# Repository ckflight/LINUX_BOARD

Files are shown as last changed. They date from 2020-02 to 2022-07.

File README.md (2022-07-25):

# Embedded Linux Board Running Custom Linux Distribution

### Project Info:

 * AT91SAM9N12 Microprocessor with Memory Management Unit based Embedded Linux Board hardware and operating system files.
It has 133 MHz RAM and 4 Gb NAND Flash and QSPI Flash Interfaces.

 * This design is the custom version of SAM9N12-EK. The custom design has a RAM with different speed and latency, also it is using NAND Flash as a memory. Therefore, AT91Bootstrap Hardware initialization files must be customized accordingly. Briefly, the PLL and clocking settings as well as RAM latency values and NAND interface pinouts are changed accordingly. To see the details of the changes, please check **LINUX_BOARD/Linux_Files/At91bootstrap Files/at91sam9n12ek.c and .h** files. 

 * Buildroot is used for custom linux distribution. Check step by step guide below for details. Follow Ubuntu, u-boot and buildroot versions strictly as indicated below to make it compile properly.

### Final Board Screenshots:



linux board



### Important Notes: 

 * Use TeraTerm on Windows or Picocom on Mac OSx to be able to set the baud rate to 118200 8bit no parity 1 stop. The reason of this baudrate is that, In AT91Bootstrap, cpu clock is configured from 400MHz to 300MHz for changing RAM speed from 133MHz to 100MHz. Since PLL multipliers are not strickly generating 300 and 100 MHz, the actual speeds are 301.333 MHz and 101.333. This main clock difference changes all other peripherals' clocking. As result of this, characters are not received correctly when the baudrate is set to 115200. When the baudrate is set to 118200 on HOST side, the hardware and the HOST side can talk without any issue. **(However in buildroot, u-boot and AT91Bootstrap files the uart is configured to 115200 8N1 no parity)**
 
 * The steps below are tested with UBUNTU 16.04.6 and 18.04.2 LTS.
 
### STEP BY STEP GUIDE FOR FLASHING BOARD TO RUN LINUX 
  
#### 1. This part describes how board is connected over USB and what commands needed to see on sam_ba program

   If linux board is new and fresh then connect over usb to linux virtual computer
   If linux board is flashed previously with files then connect nandflash's pin41 to ground and plug usb
   Linux will see device as /dev/ttyACM0 but sam_ba cannot see so type command (It is required every time): 
   
   	sudo chmod a+rw /dev/ttyACM0
   
   Or add read write permission to usb device to not write above command every time.To do that, 
   go to /etc/udev/rules.d and create a rule file such as myusb.rules file and add the line
 	
	sudo nano /etc/udev/rules.d/filename.rules
	KERNEL=="ttyACM[0-9]*",MODE="0666"

    Now sam-ba can see board as /dev/ttyACM0

#### 2. Before start install these libraries:

	1. sudo apt install libncurses5 libncursesw5-dev libncurses5-dev
	2. sudo apt install make
	3. sudo apt install gcc-arm-linux-gnueabi
	4. sudo apt install gcc
	5. sudo apt install g++
	6. sudo apt install python
        (these might no be needed)
	7. sudo apt install make-guile
	8. sudo apt install gcc-multilib
	9. sudo apt install gcc-arm*

	Files required for board and in this part they will be created:
	A. AT91SAMBOOTSTRAP 	(Initialises SAM9N12E hardware like clock, nano interface scram gpio etc.)
	B. U-BOOT    		(Initialises SAM9N12E hardware clk, ram and etc.)
	C. BUILDROOT 		(LINUX KERNEL + ROOTFS (Our python c compiler nano etc apps are in rootfs) )

#### 2.1 How to compile and create at91sambootstrap files:
 
   I put at91bootstrap-3-3.8.tar.gz, it is the latest version and works
   unzip to Ubuntu and use it. For any case download link is below:
	
	http://repository.timesys.com/buildsources/a/at91bootstrap-3/

   Go to at91bootstrap-3-3.8 folder and change 

 	/at91bootstrap-3-3.8/board/at91sam9n12ek/at91sam9n12ek.c and .h files
 
   with

 	/at91bootstrap Files/at91sam9n12ek.c and .h
 
   Go to the at91bootstrap-3-3.8 folder location over terminal and apply commands

	1. make mrproper

	2. make at91sam9n12eknf_uboot_defconfig (nf means it will be loaded to nandflash, and u-boot means it will run u-boot)

	3. make menuconfig 			(this will open a configuration window)
	   3.1.Go to RAM Configuration and change RAM size to 64M
	   3.2 Go to NAND Flash configuration and change PMECC Error Correction Bits to 4bits, Sector to 512
	   3.3 Go to U-Boot Image Storage Setup and change External Ram Address to Load U-Boot Image from
               0x26F00000 to 0x22000000
	   3.4 Save an Alternate File and it will create .config file in at91bootstrap-3-3.8.(It is invisible nano .config opens if needed.)

	4. make CROSS_COMPILE=arm-linux-gnueabi-

	RESULT: The at91sam9n12ek-nandflashboot-uboot-3.8-beta1.bin file is ready in binaries file

#### 2.2 How to compile and create u-boot files:

   I put u-boot-2015.1.tar.gz to folder no need to download newer versions since include files naming are changed
   and they are not compiling without error. Unzip it to Ubuntu and use. For any case download link is below:

	 http://repository.timesys.com/buildsources/u/u-boot/

   Go to folder and change

	u-boot-2015.01/board/atmel/at91sam9n12ek/at91sam9n12ek.c file 
	with 
	/u-boot Files/at91sam9n12ek.c

    and

	u-boot-2015.01/include/configs/at91sam9n12ek.h file 
	with	
	/u-boot Files/at91sam9n12ek.h
	
    also For Ubuntu 16.04 gcc5.h, For Ubuntu 18.04 gcc7.h add (they have same code inside as well)

	/u-boot Files/compiler-gcc5.h or gcc.7 file
	to
	u-boot-2015.01/include/linux folder

   Go to u-boot-2015.01 folder with terminal and apply commands

	1. make mrproper

	2. make at91sam9n12ek_nandflash_defconfig (nandflash means this file will be written to nandflash)

	3. make CROSS_COMPILE=arm-linux-gnueabi-

	RESULT: The u-boot.bin is in u-boot-2015.01 folder

#### 2.3 How to compile and create build root files:
   
   I put buildroot-2015.2.tar.gz to folder and this version works. For any case download link is below:

	https://buildroot.org/downloads/

   Before start: Buildroot might create errors during compile. 
                 These are mostly package version collision type errors.
                 I look for error file and try to correct them. 
		 If i cannot then i disable that package with "make menuconfig" window.
                 Update when Ubuntu 16.04 is used: In buildroot-2015.2 it gave error i added correction files
		 Update when Ubuntu 18.04 is used: In buildroot-2015.2 it gave error i added correction files

   I used ready linux binary tree files with config files. (Read Linux Embedded Notes 5. DEVICE TREE: part for details of device tree .dts file)
  
   Go to /Buildroot_Files folder and copy 3 files from

	/Buildroot Files/
	to
	/buildroot-2015.02 main folder

   and then rename config-buildroot file as .config (it will be invisible after name change use terminal to see)

   Go to the buildroot-2015.02 folder and apply commands

	(To configure linux kernel to enable drivers use "make linux-menuconfig" command)
   	(for example wifi usb dongle drivers are enabled in linux menuconfig)

	1. make mrproper or make clean

	2. make menuconfig(if i want to add or change something)

	3. make

	RESULT: The files are in buildroot-2015.02/output/images

   Correction if Ubuntu 2016.04 is used (These can be applied when they occur during compilation): 
   	
	if an error not listed below happens first try to remove the installed package from "/output/build" and make again	

	a. ncrses:		copy the code in Buildroot_Correction/ncrse5.9_correction/MKlib_gen.sh 
                                and paste inside of (do not copy paste files itself copy paste code)
                                buildroot-2015.02/output/build/host-crse5.9/ncrse/base/Mklib_gen.sh
	
	c. host-mtd1.5.1: 	(DO THIS TO HOST-MTD NOT MTD folder) copy the code Buildroot_Correction/mkfsutil_correction
                                and paste to (do not copy paste file)
				buildroot-2015.02/output/build/host-mtd1.5.1/mkfs.ubifs/hashtable

   Correction if Ubuntu 2018.04 is with gcc 5 used (These can be applied when they occur during compilation):
   (All error corrections are added below. If could not make it work use Ubuntu 16.04) 
   	
	a. libffi3.1: 		change Buildroot_Correction/libffi3.1_correction/automake file 
				with 
				buildroot-2015.02/output/host/user/bin/automake
	
	b. libglib2.42:         (DO THIS TO LIBGLIB NOT HOST-LIBGLIB folder) change Buildroot_Correction/libglib2.42_correction/gdate.c file
				with
				buildroot-2015.02/output/build/libglib2.42/glib/gdate.c

	c. lzop1.03:            copy the code Buildroot_Correction/lzop1.03_correction/miniacc.f file
                                and paste to (do not copy paste file)
				buildroot-2015.02/output/build/host-lzop1.03/src/miniacc.h

	d. ncrses:		copy the code Buildroot_Correction/ncrse5.9_correction/MKlib_gen.sh 
                                and paste to (do not copy paste file)
                                buildroot-2015.02/output/build/host-crse5.9/ncrse/base/Mklib_gen.sh
	
	e. host-mtd1.5.1: 	(DO THIS TO HOST-MTD NOT MTD folder) copy the code Buildroot_Correction/mkfsutil_correction
                                and paste to (do not copy paste file)
				buildroot-2015.02/output/build/host-mtd1.5.1/mkfs.ubifs/hashtable

#### 3. How to flash files to board:

   Memory locations of files
	
	* at91sam9n12ek-nandflashboot-uboot-3.8.bin -----> 0x00

	* u-boot.bin				     -----> 0x40000

	* at91sam9n12_sam_board_3.15.dtb	     -----> 0x180000

	* uImage.bin				     -----> 0x200000

	* rootfs.ubi				     -----> 0x800000

   Unzip /sam-ba to ubuntu and connect board over usb (see 1) then click connect.
   Select "NandFlash" tab and from Scripts select "Enable NandFlash" click execute button.
   It should print as below:

	-I- NANDFLASH::Init (trace level : 4)
	-I- Loading applet applet-nandflash-sam9n12.bin at address 0x20000000
	-I- Memory Size : 0x20000000 bytes
	-I- Buffer address : 0x20011404
	-I- Buffer size: 0x20000 bytes
	-I- Applet initialization done

   Then again from Scripts select "Pmecc configuration" click execute button.
   (I think it reads nandflash auto but do anyway because when wrong parameters selected it gives error.)
   Select ECC bit: 4
   Select Sector size: 512

   It should print as below:
	-I- Ecc type is 2 Ecc Status is 2
	-I- Configure trimffs 0
	-I- PMECC c0082805 to be Configured
	-I- Pmecc header configration successful
	-I- PMECC configure c0082805   

#### 3.1. Set Address to 0x00 and from Scripts select "Send Boot File" click execute button.  
      Select at91sam9n12ek-nandflashboot-uboot-3.8.bin file and click open.

      It should print as below:
	   -I- Sending boot file done.

   From now on execute button will not be used. Rest of the files will send with
   "Send File Name" folder selector and address setting.

#### 3.2. Set Address to 0x40000 and from "Send File Name" folder selector 
      select "u-boot.bin" file and click "Send File".

      It should print as below:
	   -I- Send File /home/ck/Desktop/u-boot.bin at address 0x40000
	   GENERIC::SendFile /home/ck/Desktop/u-boot.bin at address 0x40000
	   -I- File size : 0x5CD30 byte(s)
	   -I- 	Writing: 0x20000 bytes at 0x40000 (buffer addr : 0x20011404)
	   -I- 	0x20000 bytes written by applet
	   -I- 	Writing: 0x20000 bytes at 0x60000 (buffer addr : 0x20011404)
	   -I- 	0x20000 bytes written by applet
	   -I- 	Writing: 0x1CD30 bytes at 0x80000 (buffer addr : 0x20011404)
	   -I- 	0x1CD30 bytes written by applet

#### 3.3. Set Address to 0x180000 and from "Send File Name" folder selector 
      select "at91sam9n12_sam_board_3.15.dtb" file and click "Send File".
      
      It should print as below:
	   -I- Send File /home/ck/Desktop/at91sam9n12_sam_board_3.15.dtb at address 0x180000
	   GENERIC::SendFile /home/ck/Desktop/at91sam9n12_sam_board_3.15.dtb at address 0x180000
	   -I- File size : 0x2966 byte(s)
	   -I- 	Writing: 0x2966 bytes at 0x180000 (buffer addr : 0x20011404)
	   -I- 	0x20000 bytes written by applet

#### 3.4. Set Address to 0x200000 and from "Send File Name" folder selector 
      select "uImage.bin" file and click "Send File".
      
      It should print as below:

	   -I- Send File /home/ck/Desktop/uImage.bin at address 0x200000
	   GENERIC::SendFile /home/ck/Desktop/uImage.bin at address 0x200000
	   -I- File size : 0x2B91F0 byte(s)
	   -I- 	Writing: 0x20000 bytes at 0x200000 (buffer addr : 0x20011404)
	   -I- 	0x20000 bytes written by applet
	   ... goes like this
	   -I- 	Writing: 0x191F0 bytes at 0x4A0000 (buffer addr : 0x20011404)
	   -I- 	0x191F0 bytes written by applet

#### 3.5. Set Address to 0x800000 and from "Send File Name" folder selector 
      select "rootfs.ubi" file and click "Send File".

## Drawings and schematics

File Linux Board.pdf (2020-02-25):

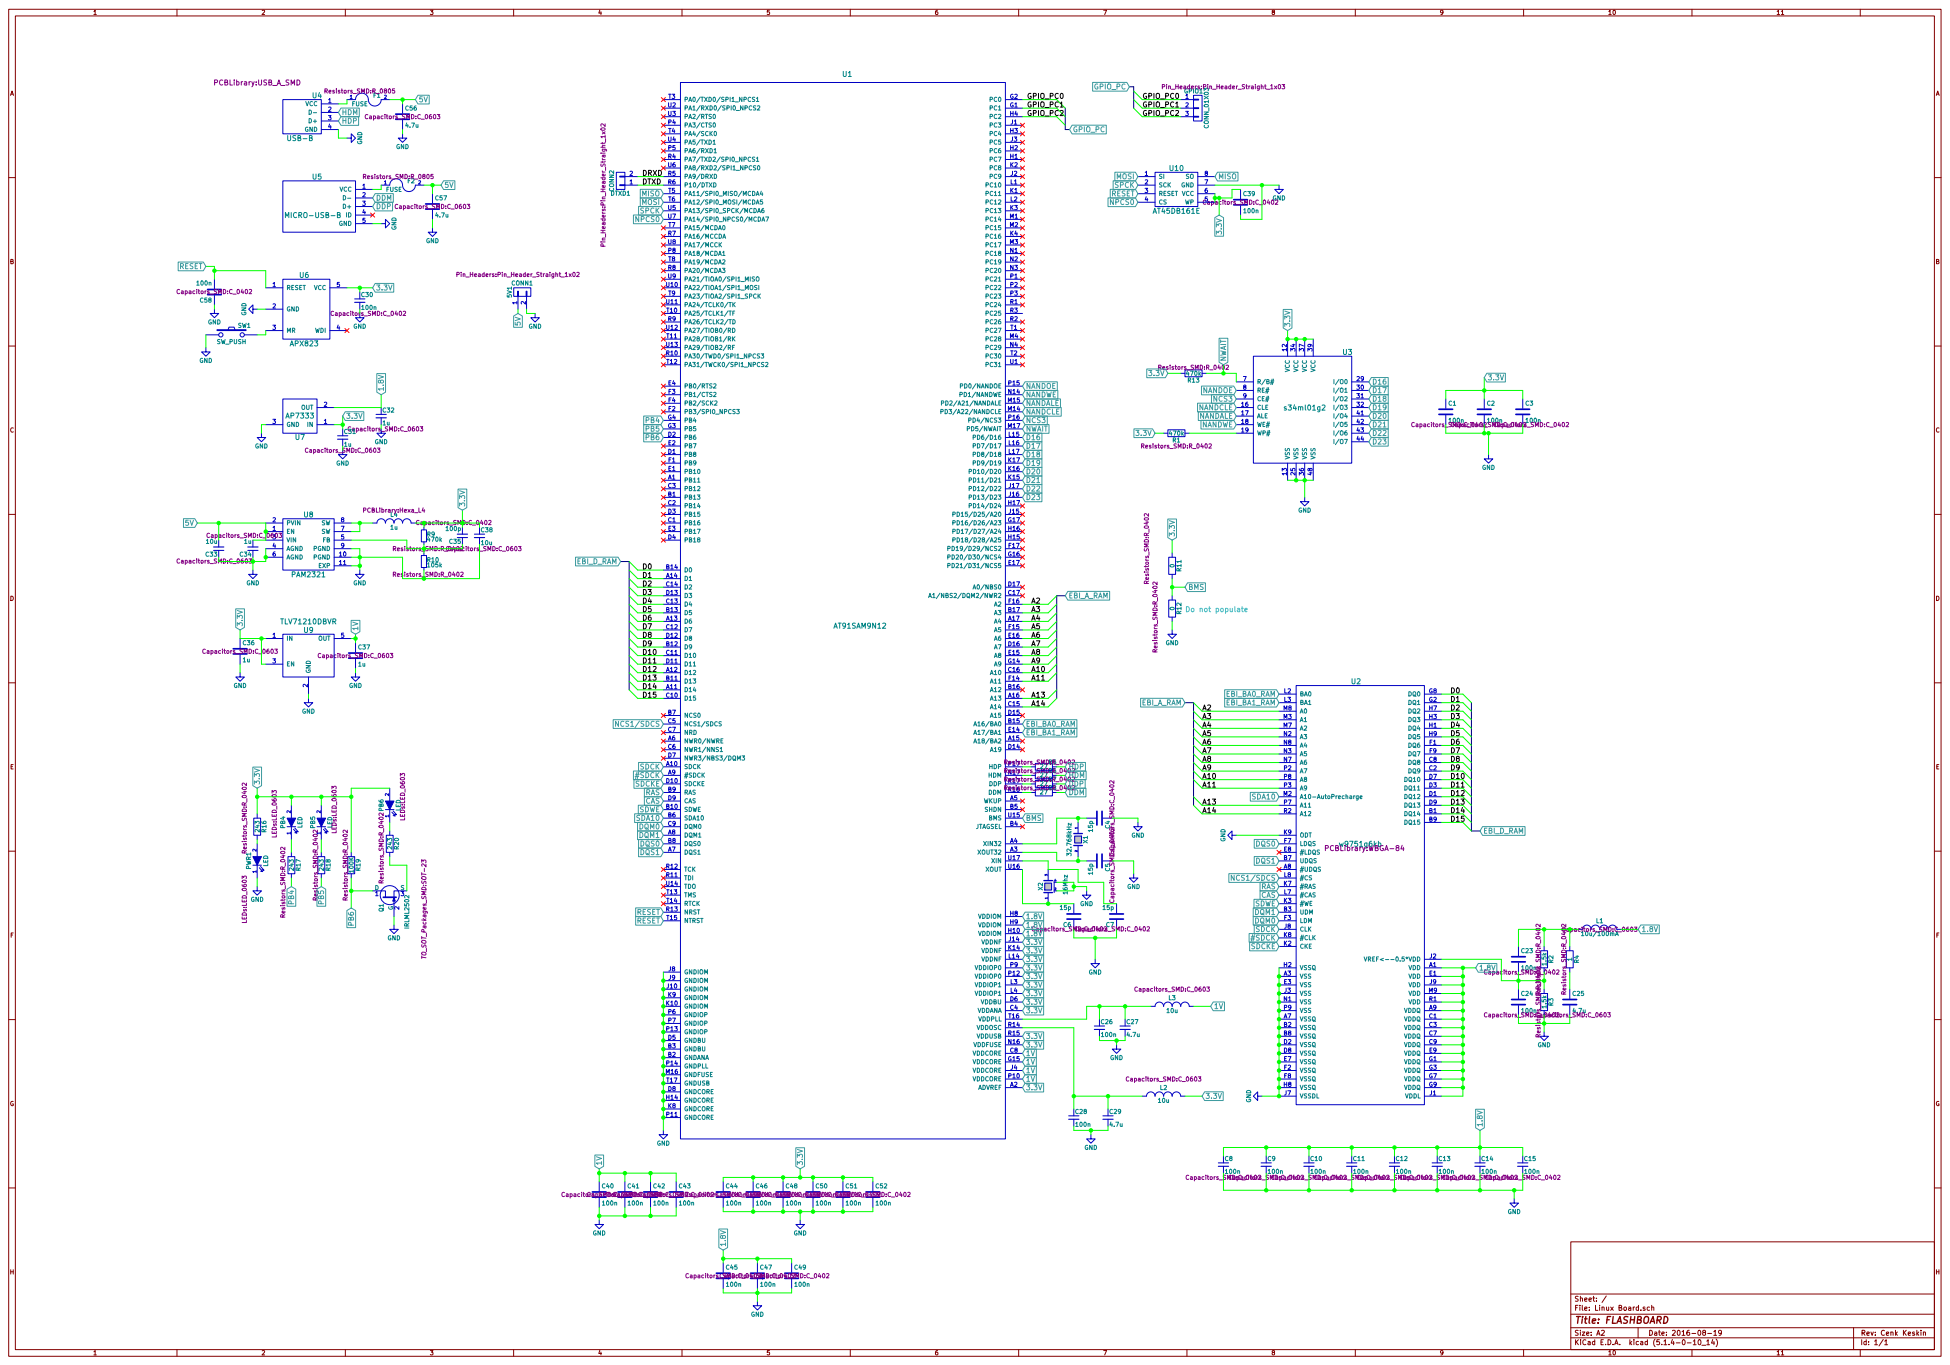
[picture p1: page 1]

File: Linux Board.sch Sheet: /
Id: 1/1 Title: FLASHBOARD

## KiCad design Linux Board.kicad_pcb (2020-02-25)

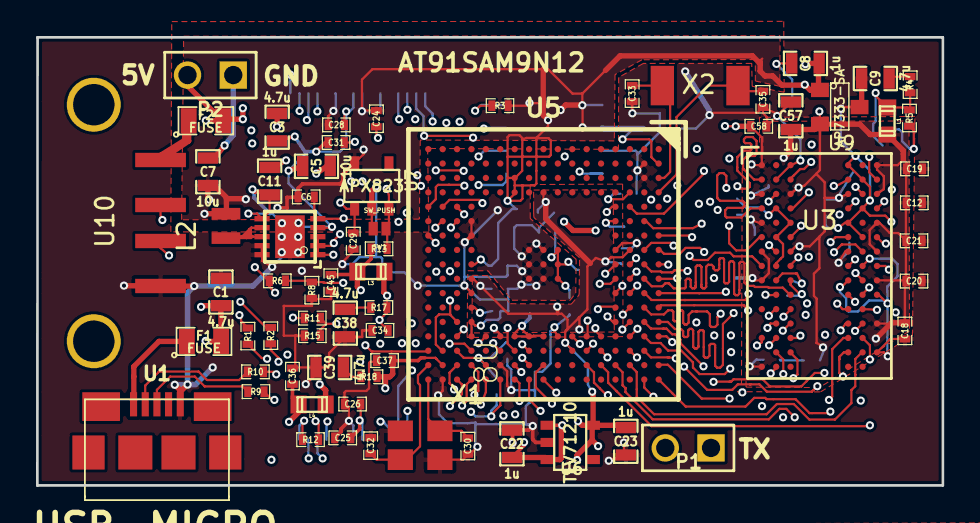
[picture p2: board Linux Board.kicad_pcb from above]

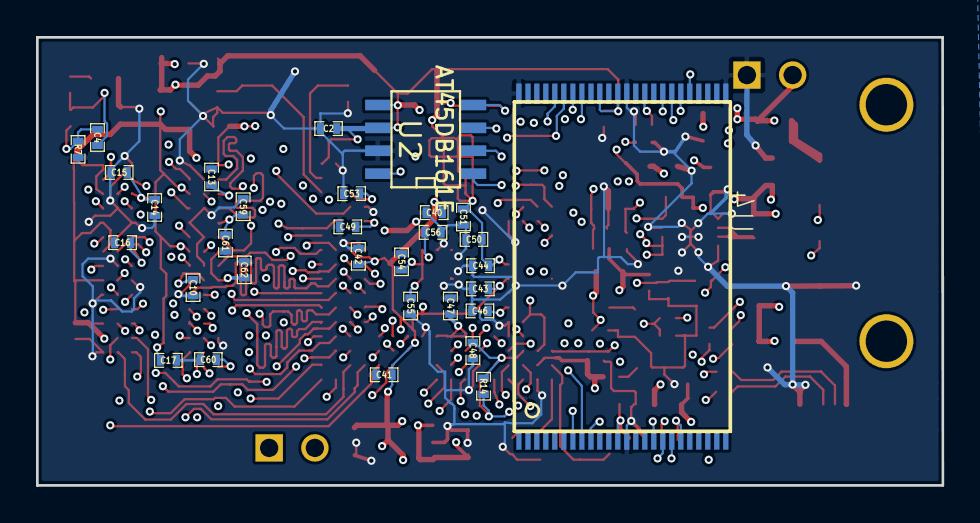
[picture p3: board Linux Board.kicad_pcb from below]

Board: 4 copper layers, 50.3 x 24.9 mm, 98 parts (31 on the bottom side), 94 nets.

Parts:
C1, C3, C9, C38, C39: 4.7u; SM0603_Capa
C2, C4, C10, C12, C13, C14, C15, C16, C17, C18, C19, C20, C21, C24, C25, C26, C28, C29, C31, C34, C36, C37, C40, C41, C42, C43, C44, C45, C46, C47, C48, C49, C50, C51, C53, C54, C55, C56, C58, C59, C60, C61, C62: 100n; SM0402_c
C5, C7: 10u; SM0603_Capa
C6: 100p; SM0402_c
C8, C11, C22, C23, C57: 1u; SM0603_Capa
C30, C32, C33, C35: 15p; SM0402_c
F1, F2: FUSE; SM0805
L1, L3, L4: 10u/100mA; c_0603
L2: 1.0u/1.5A; VLS201612E
P1, P2: CONN_2; PIN_ARRAY_2X1
R1, R2, R9, R10: 27; SM0402_r
R3, R12, R14: 470k; SM0402_r
R4, R17, R18: 1; SM0402_r
R5, R7: 1.5k; SM0402_r
R6: 450k; SM0402_r
R8: 100k; SM0402_r
R11, R15: 0; SM0402_r
R13: 10k; SM0402_r
SW1: SW_PUSH; S_JUMPER_2
U1: USB-MICRO; MICRO-B_USB
U2: AT45DB161E; SO8E
U3: W9751G6KB; WBGA-84
U4: PAM2321; DFN10-3X3
U5: AT91SAM9N12; lfbga217-std
U6: TLV71210; SOT23-5
U7: APX823; SOT23-5
U8: S34ML04G2; TSOP48
U9: AP7333-SA; SOT23
U10: USB-A; USB-A-SMD
X1: 16MHz; TSX-3225
X2: 32.768kHz; ABS10

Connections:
1V: C23.1, C36.1, C40.1, C41.1, C42.1, C43.1, L4.1, U5.C8, U5.G15, U5.J4, U5.P10, U6.5
3V3: C2.1, C6.1, C7.1, C8.1, C22.1, C24.1, C25.1, C26.1, C28.1, C44.1, C45.1, C46.1, C47.1, C48.1, C49.1, C50.1, C51.1, C53.1, L2.2, L3.1, R3.2, R6.1, R11.2, R12.1, R13.1, R14.2, U2.5, U2.6, U5.A2, U5.C4, U5.D6, U5.J14, U5.K14, U5.L3, U5.L4, U5.L14, U5.N16, U5.P9, U5.P12, U5.R15, U6.1, U6.3, U7.5, U8.12, U8.34, U8.37, U8.39, U9.1
5V: C1.1, C3.1, C5.1, C11.1, F1.2, F2.2, P2.2, U4.1, U4.2, U4.3
+1.8V: C12.1, C13.1, C14.1, C15.1, C16.1, C17.1, C18.1, C19.1, C20.1, C21.1, C54.1, C55.1, C56.1, C57.1, C58.1, C59.1, C60.1, C61.1, C62.1, L1.1, U3.A1, U3.A9, U3.C1, U3.C3, U3.C7, U3.C9, U3.E1, U3.E9, U3.G1, U3.G3, U3.G7, U3.G9, U3.J1, U3.J9, U3.M9, U3.R1, U5.H8, U5.H9, U5.H10, U9.2
/A2: U3.M8, U5.F16
/A3: U3.M3, U5.B17
/A4: U3.M7, U5.A17
/A5: U3.N2, U5.F15
/A6: U3.N8, U5.E16
/A7: U3.N3, U5.D16
/A8: U3.N7, U5.E15
/A9: U3.P2, U5.G14
/A10: U3.P8, U5.C16
/A11: U3.P3, U5.F14
/A13: U3.P7, U5.A16
/A14: U3.R2, U5.C15
/A16/BA0: U3.L2, U5.B15
/A17/BA1: U3.L3, U5.E14
/CAS: U3.L7, U5.D9
/D0: U3.G8, U5.B14
/D1: U3.G2, U5.A14
/D2: U3.H7, U5.C14
/D3: U3.H3, U5.D13
/D4: U3.H1, U5.C13
/D5: U3.H9, U5.B13
/D6: U3.F1, U5.A13
/D7: U3.F9, U5.C12
/D8: U3.C8, U5.D12
/D9: U3.C2, U5.B12
/D10: U3.D7, U5.C11
/D11: U3.D3, U5.D11
/D12: U3.D1, U5.A12
/D13: U3.D9, U5.B11
/D14: U3.B1, U5.A11
/D15: U3.B9, U5.C10
/D16: U5.L15, U8.29
/D17: U5.L16, U8.30
/D18: U5.L17, U8.31
/D19: U5.K17, U8.32
/D20: U5.K16, U8.41
/D21: U5.K15, U8.42
/D22: U5.J17, U8.43
/D23: U5.J16, U8.44
/DQM0: U3.F3, U5.C9
/DQM1: U3.B3, U5.A8
/DQS0: U3.F7, U5.B8
/DQS1: U3.B7, U5.A7
/DRXD: P1.2, U5.R5
/DTXD: P1.1, U5.R6
/MISO0: U2.8, U5.T5
/MOSI0: U2.1, U5.T6
/NANDALE: U5.M15, U8.17
/NANDCLE: U5.M14, U8.16
/NANDCS: U5.P16, U8.9
/NANDOE: U5.P15, U8.8
/NANDWE: U5.N14, U8.18
/NCS1: U3.L8, U5.C5
/NPCS0: R3.1, U2.4, U5.U7
/NWAIT: R14.1, U5.M17, U8.7
/RAS: U3.K7, U5.B9
/SCK0: U2.2, U5.U5
/SDA10: U3.M2, U5.B6
/SDCK: U3.J8, U5.A10
/SDCKE: U3.K2, U5.D10
/SDCKN: U3.K8, U5.A9
/SDWE: U3.K3, U5.B10
/VDD_OSC: C34.1, L3.2, R17.2, U5.R14
/VDD_PLL: C37.1, L4.2, R18.2, U5.T16
GND: C1.2, C2.2, C3.2, C5.2, C7.2, C8.2, C9.2, C10.2, C11.2, C12.2, C13.2, C14.2, C15.2, C16.2, C17.2, C18.2, C19.2, C20.2, C21.2, C22.2, C23.2, C24.2, C25.2, C26.2, C28.2, C29.2, C30.1, C31.2, C32.1, C33.2, C34.2, C35.2, C36.2, C37.2, C38.2, C39.2, C40.2, C41.2, C42.2, C43.2, C44.2, C45.2, C46.2, C47.2, C48.2, C49.2, C50.2, C51.2, C53.2, C54.2, C55.2, C56.2, C57.2, C58.2, C59.2, C60.2, C61.2, C62.2, P2.1, R7.2, R8.1, R15.1, SW1.2, U1.5, U2.7, U3.A3, U3.A7, U3.B2, U3.B8, U3.D2, U3.D8, U3.E3, U3.E7, U3.F2, U3.F8, U3.H2, U3.H8, U3.J3, U3.J7, U3.K9, U3.N1, U3.P9, U4.4, U4.6, U4.9, U4.10, U4.EXP, U5.B2, U5.B3, U5.D5, U5.D8, U5.H14, U5.J8, U5.J9, U5.J10, U5.K8, U5.K9, U5.K10, U5.M16, U5.P6, U5.P7, U5.P11, U5.P13, U5.P14, U5.T17, U6.2, U7.2, U8.13, U8.25, U8.36, U8.48, U9.3, U10.4, X1.2, X1.4
unnamed: C4.2, C10.1, R5.2, R7.1, U3.J2
unnamed: L2.1, U4.7, U4.8
unnamed: C38.1, R17.1
unnamed: C6.2, R6.2, R8.2, U4.5
unnamed: F2.1, U10.1
unnamed: R2.1, U5.N17
unnamed: R1.1, U5.P17
unnamed: R12.2, U8.19
unnamed: C32.2, U5.U16, X1.1
unnamed: C39.1, R18.1
unnamed: C9.1, R4.2
unnamed: F1.1, U1.1
unnamed: R10.1, U5.R16
unnamed: R9.1, U5.R17
unnamed: R11.1, R15.2, U5.U15
unnamed: C31.1, R13.2, SW1.1, U7.3
unnamed: C30.2, U5.U17, X1.3
unnamed: C4.1, L1.2, R4.1, R5.1
unnamed: C35.1, U5.A4, X2.2
unnamed: C33.1, U5.A3, X2.1
USBDM: R10.2, U1.2
USBDP: R9.2, U1.3
USBHM: R2.2, U10.2
USBHP: R1.2, U10.3
~RESET: C29.1, U2.3, U5.R13, U5.T15, U7.1

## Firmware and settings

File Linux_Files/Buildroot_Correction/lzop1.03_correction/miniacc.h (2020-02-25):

/* ACC --- Automatic Compiler Configuration

   This file is part of the lzop file compressor.

   Copyright (C) 2010 Markus Franz Xaver Johannes Oberhumer
   Copyright (C) 2009 Markus Franz Xaver Johannes Oberhumer
   Copyright (C) 2008 Markus Franz Xaver Johannes Oberhumer
   Copyright (C) 2007 Markus Franz Xaver Johannes Oberhumer
   Copyright (C) 2006 Markus Franz Xaver Johannes Oberhumer
   Copyright (C) 2005 Markus Franz Xaver Johannes Oberhumer
   Copyright (C) 2004 Markus Franz Xaver Johannes Oberhumer
   Copyright (C) 2003 Markus Franz Xaver Johannes Oberhumer
   Copyright (C) 2002 Markus Franz Xaver Johannes Oberhumer
   Copyright (C) 2001 Markus Franz Xaver Johannes Oberhumer
   Copyright (C) 2000 Markus Franz Xaver Johannes Oberhumer
   Copyright (C) 1999 Markus Franz Xaver Johannes Oberhumer
   Copyright (C) 1998 Markus Franz Xaver Johannes Oberhumer
   Copyright (C) 1997 Markus Franz Xaver Johannes Oberhumerf
   Copyright (C) 1996 Markus Franz Xaver Johannes Oberhumer
   All Rights Reserved.

   lzop and the LZO library are free software; you can redistribute them
   and/or modify them under the terms of the GNU General Public License as
   published by the Free Software Foundation; either version 2 of
   the License, or (at your option) any later version.

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
   You should have received a copy of the GNU General Public License
   along with this program; see the file COPYING.
   If not, write to the Free Software Foundation, Inc.,
   59 Temple Place - Suite 330, Boston, MA 02111-1307, USA.

   Markus F.X.J. Oberhumer
   <markus@oberhumer.com>
   http://www.oberhumer.com/opensource/lzop/
 */


#ifndef __ACC_H_INCLUDED
#define __ACC_H_INCLUDED 1
#define ACC_VERSION     20101019L
#if defined(__CYGWIN32__) && !defined(__CYGWIN__)
#  define __CYGWIN__ __CYGWIN32__
#endif
#if defined(__IBMCPP__) && !defined(__IBMC__)
#  define __IBMC__ __IBMCPP__
#endif
#if defined(__ICL) && defined(_WIN32) && !defined(__INTEL_COMPILER)
#  define __INTEL_COMPILER __ICL
#endif
#if 1 && defined(__INTERIX) && defined(__GNUC__) && !defined(_ALL_SOURCE)
#  define _ALL_SOURCE 1
#endif
#if defined(__mips__) && defined(__R5900__)
#  if !defined(__LONG_MAX__)
#    define __LONG_MAX__ 9223372036854775807L
#  endif
#endif
#if defined(__INTEL_COMPILER) && defined(__linux__)
#  pragma warning(disable: 193)
#endif
#if defined(__KEIL__) && defined(__C166__)
#  pragma warning disable = 322
#elif 0 && defined(__C251__)
#  pragma warning disable = 322
#endif
#if defined(_MSC_VER) && !defined(__INTEL_COMPILER) && !defined(__MWERKS__)
#  if (_MSC_VER >= 1300)
#    pragma warning(disable: 4668)
#  endif
#endif
#if defined(__POCC__) && defined(_WIN32)
#  if (__POCC__ >= 400)
#    pragma warn(disable: 2216)
#  endif
#endif
#if 0 && defined(__WATCOMC__)
#  if (__WATCOMC__ >= 1050) && (__WATCOMC__ < 1060)
#    pragma warning 203 9
#  endif
#endif
#if defined(__BORLANDC__) && defined(__MSDOS__) && !defined(__FLAT__)
#  pragma option -h
#endif
#if (ACC_CFG_NO_CONFIG_HEADER)
#elif defined(ACC_CFG_CONFIG_HEADER)
#  include ACC_CFG_CONFIG_HEADER
#else
#endif
#if (ACC_CFG_NO_LIMITS_H)
#elif (ACC_LIBC_NAKED) || (ACC_BROKEN_LIMITS_H)
#ifndef __ACC_FALLBACK_LIMITS_H_INCLUDED
#define __ACC_FALLBACK_LIMITS_H_INCLUDED 1
#undef CHAR_BIT
#define CHAR_BIT        8
#ifndef MB_LEN_MAX
#define MB_LEN_MAX      1
#endif
#ifndef __SCHAR_MAX__
#define __SCHAR_MAX__   127
#endif
#ifndef __SHRT_MAX__
#define __SHRT_MAX__    32767
#endif
#ifndef __INT_MAX__
#define __INT_MAX__     2147483647
#endif
#ifndef __LONG_MAX__
#if defined(__alpha__) || defined(_LP64) || defined(__MIPS_PSX2__)
#define __LONG_MAX__    9223372036854775807L
#else
#define __LONG_MAX__    2147483647L
#endif
#endif
#undef SCHAR_MIN
#undef SCHAR_MAX
#undef UCHAR_MAX
#define SCHAR_MIN       (-1 - SCHAR_MAX)
#define SCHAR_MAX       (__SCHAR_MAX__)
#define UCHAR_MAX       (SCHAR_MAX * 2 + 1)
#undef SHRT_MIN
#undef SHRT_MAX
#undef USHRT_MAX
#define SHRT_MIN        (-1 - SHRT_MAX)
#define SHRT_MAX        (__SHRT_MAX__)
#if ((__INT_MAX__) == (__SHRT_MAX__))
#define USHRT_MAX       (SHRT_MAX * 2U + 1U)
#else
#define USHRT_MAX       (SHRT_MAX * 2 + 1)
#endif
#undef INT_MIN
#undef INT_MAX
#undef UINT_MAX
#define INT_MIN         (-1 - INT_MAX)
#define INT_MAX         (__INT_MAX__)
#define UINT_MAX        (INT_MAX * 2U + 1U)
#undef LONG_MIN
#undef LONG_MAX
#undef ULONG_MAX
#define LONG_MIN        (-1L - LONG_MAX)
#define LONG_MAX        ((__LONG_MAX__) + 0L)
#define ULONG_MAX       (LONG_MAX * 2UL + 1UL)
#undef CHAR_MIN
#undef CHAR_MAX
#if defined(__CHAR_UNSIGNED__) || defined(_CHAR_UNSIGNED)
#define CHAR_MIN        0
#define CHAR_MAX        UCHAR_MAX
#else
#define CHAR_MIN        SCHAR_MIN
#define CHAR_MAX        SCHAR_MAX
#endif
#endif
#else
#  include <limits.h>
#endif
#if 0
#define ACC_0xffffL             0xfffful
#define ACC_0xffffffffL         0xfffffffful
#else
#define ACC_0xffffL             65535ul
#define ACC_0xffffffffL         4294967295ul
#endif
#if (ACC_0xffffL == ACC_0xffffffffL)
#  error "your preprocessor is broken 1"
#endif
#if (16ul * 16384ul != 262144ul)
#  error "your preprocessor is broken 2"
#endif
#if 0
#if (32767 >= 4294967295ul)
#  error "your preprocessor is broken 3"
#endif
#if (65535u >= 4294967295ul)
#  error "your preprocessor is broken 4"
#endif
#endif
#if (UINT_MAX == ACC_0xffffL)
#if defined(__ZTC__) && defined(__I86__) && !defined(__OS2__)
#  if !defined(MSDOS)
#    define MSDOS 1
#  endif
#  if !defined(_MSDOS)
#    define _MSDOS 1
#  endif
#elif 0 && defined(__VERSION) && defined(MB_LEN_MAX)
#  if (__VERSION == 520) && (MB_LEN_MAX == 1)
#    if !defined(__AZTEC_C__)
#      define __AZTEC_C__ __VERSION
#    endif
#    if !defined(__DOS__)
#      define __DOS__ 1
#    endif
#  endif
#endif
#endif
#if defined(_MSC_VER) && defined(M_I86HM) && (UINT_MAX == ACC_0xffffL)
#  define ptrdiff_t long
#  define _PTRDIFF_T_DEFINED 1
#endif
#if (UINT_MAX == ACC_0xffffL)
#  undef __ACC_RENAME_A
#  undef __ACC_RENAME_B
#  if defined(__AZTEC_C__) && defined(__DOS__)
#    define __ACC_RENAME_A 1
#  elif defined(_MSC_VER) && defined(MSDOS)
#    if (_MSC_VER < 600)
#      define __ACC_RENAME_A 1
#    elif (_MSC_VER < 700)
#      define __ACC_RENAME_B 1
#    endif
#  elif defined(__TSC__) && defined(__OS2__)
#    define __ACC_RENAME_A 1
#  elif defined(__MSDOS__) && defined(__TURBOC__) && (__TURBOC__ < 0x0410)
#    define __ACC_RENAME_A 1
#  elif defined(__PACIFIC__) && defined(DOS)
#    if !defined(__far)
#      define __far far
#    endif
#    if !defined(__near)
#      define __near near
#    endif
#  endif
#  if defined(__ACC_RENAME_A)
#    if !defined(__cdecl)
#      define __cdecl cdecl
#    endif
#    if !defined(__far)
#      define __far far
#    endif
#    if !defined(__huge)
#      define __huge huge
#    endif
#    if !defined(__near)
#      define __near near
#    endif
#    if !defined(__pascal)
#      define __pascal pascal
#    endif
#    if !defined(__huge)
#      define __huge huge
#    endif
#  elif defined(__ACC_RENAME_B)
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

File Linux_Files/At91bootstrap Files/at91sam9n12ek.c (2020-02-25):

/* ----------------------------------------------------------------------------
 *         ATMEL Microcontroller Software Support
 * ----------------------------------------------------------------------------
 * Copyright (c) 2008, Atmel Corporation

 * All rights reserved.
 *
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
 * Atmel's name may not be used to endorse or promote products derived from
 * this software without specific prior written permission.
 *
 * DISCLAIMER: THIS SOFTWARE IS PROVIDED BY ATMEL "AS IS" AND ANY EXPRESS OR
 * IMPLIED WARRANTIES, INCLUDING, BUT NOT LIMITED TO, THE IMPLIED WARRANTIES OF
 * MERCHANTABILITY, FITNESS FOR A PARTICULAR PURPOSE AND NON-INFRINGEMENT ARE
 * DISCLAIMED. IN NO EVENT SHALL ATMEL BE LIABLE FOR ANY DIRECT, INDIRECT,
 * INCIDENTAL, SPECIAL, EXEMPLARY, OR CONSEQUENTIAL DAMAGES (INCLUDING, BUT NOT
 * LIMITED TO, PROCUREMENT OF SUBSTITUTE GOODS OR SERVICES; LOSS OF USE, DATA,
 * OR PROFITS; OR BUSINESS INTERRUPTION) HOWEVER CAUSED AND ON ANY THEORY OF
 * LIABILITY, WHETHER IN CONTRACT, STRICT LIABILITY, OR TORT (INCLUDING
 * NEGLIGENCE OR OTHERWISE) ARISING IN ANY WAY OUT OF THE USE OF THIS SOFTWARE,
 * EVEN IF ADVISED OF THE POSSIBILITY OF SUCH DAMAGE.
 */
#include "common.h"
#include "hardware.h"
#include "arch/at91_ccfg.h"
#include "arch/at91_rstc.h"
#include "arch/at91_pmc.h"
#include "arch/at91_smc.h"
#include "arch/at91_pio.h"
#include "arch/at91_ddrsdrc.h"
#include "gpio.h"
#include "pmc.h"
#include "usart.h"
#include "debug.h"
#include "ddramc.h"
#include "spi.h"
#include "slowclk.h"
#include "timer.h"
#include "watchdog.h"
#include "string.h"
#include "at91sam9n12ek.h"

#ifdef CONFIG_USER_HW_INIT
extern void hw_init_hook(void);
#endif

static void at91_dbgu_hw_init(void)
{
	/* Configure DBGU pin */
	const struct pio_desc dbgu_pins[] = {
		{"RXD", AT91C_PIN_PA(9), 0, PIO_DEFAULT, PIO_PERIPH_A},
		{"TXD", AT91C_PIN_PA(10), 0, PIO_DEFAULT, PIO_PERIPH_A},
		{(char *)0, 0, 0, PIO_DEFAULT, PIO_PERIPH_A},
	};

	/*  Configure the dbgu pins */
	pmc_enable_periph_clock(AT91C_ID_PIOA_B);
	pio_configure(dbgu_pins);
}

static void initialize_dbgu(void)
{
	at91_dbgu_hw_init();
	usart_init(BAUDRATE(MASTER_CLOCK, 115200));
}

#ifdef CONFIG_DDR2
/* Using the Micron MT47H64M16HR-3 */
static void ddramc_reg_config(struct ddramc_register *ddramc_config)
{
	ddramc_config->mdr = (AT91C_DDRC2_DBW_16_BITS
				| AT91C_DDRC2_MD_DDR2_SDRAM);

	ddramc_config->cr = (AT91C_DDRC2_NC_DDR10_SDR9	// 10 column bits (1K)
				| AT91C_DDRC2_NR_13	// 13 row bits    (8K)
				| AT91C_DDRC2_CAS_3	// CAS Latency 3
				| AT91C_DDRC2_NB_BANKS_4	// 8 banks
				| AT91C_DDRC2_DLL_RESET_DISABLED	// DLL not reset
				| AT91C_DDRC2_DECOD_INTERLEAVED);	// Interleaved decoding

	/*
	 * The DDR2-SDRAM device requires a refresh every 15.625 us or 7.81 us.
	 * With a 133 MHz frequency, the refresh timer count register must to be
	 * set with (15.625 x 133 MHz) ~ 2084 i.e. 0x824
	 * or (7.81 x 133 MHz) ~ 1040 i.e. 0x410.
	 */
	ddramc_config->rtr = 0x30D;	/* Refresh timer: 7.8125us */

	/* One clock cycle @ 133 MHz = 7.5 ns */
	ddramc_config->t0pr = (AT91C_DDRC2_TRAS_(2)
				| AT91C_DDRC2_TRCD_(2)
				| AT91C_DDRC2_TWR_(2)
				| AT91C_DDRC2_TRC_(6)
				| AT91C_DDRC2_TRP_(2)
				| AT91C_DDRC2_TRRD_(1)
				| AT91C_DDRC2_TWTR_(2)
				| AT91C_DDRC2_TMRD_(2));

	ddramc_config->t1pr = (AT91C_DDRC2_TXP_(2)
				| AT91C_DDRC2_TXSRD_(200)
				| AT91C_DDRC2_TXSNR_(12)
				| AT91C_DDRC2_TRFC_(11));

	ddramc_config->t2pr = (AT91C_DDRC2_TRTP_(2)
				| AT91C_DDRC2_TRPA_(2)
				| AT91C_DDRC2_TXARDS_(8)
				| AT91C_DDRC2_TXARD_(3));
}

static void ddramc_init(void)
{
	unsigned long csa;
	struct ddramc_register ddramc_reg;

	ddramc_reg_config(&ddramc_reg);

	/* ENABLE DDR2 clock */
	pmc_enable_system_clock(AT91C_PMC_DDR);

	/* Chip select 1 is for DDR2/SDRAM */
	csa = readl(AT91C_BASE_CCFG + CCFG_EBICSA);
	csa |= AT91C_EBI_CS1A_SDRAMC;
	csa &= ~AT91C_EBI_DBPUC;
	csa |= AT91C_EBI_DBPDC;
	csa |= AT91C_EBI_DRV_HD;

	writel(csa, AT91C_BASE_CCFG + CCFG_EBICSA);

	/* DDRAM2 Controller initialize */
	ddram_initialize(AT91C_BASE_DDRSDRC, AT91C_BASE_CS1, &ddramc_reg);
}
#endif /* #ifdef CONFIG_DDR2 */

#if defined(CONFIG_NANDFLASH_RECOVERY) || defined(CONFIG_DATAFLASH_RECOVERY)
static void recovery_buttons_hw_init(void)
{
	/* Configure recovery button PINs */
	const struct pio_desc recovery_button_pins[] = {
		{"RECOVERY_BUTTON", CONFIG_SYS_RECOVERY_BUTTON_PIN, 0, PIO_PULLUP, PIO_INPUT},
		{(char *)0, 0, 0, PIO_DEFAULT, PIO_PERIPH_A},
	};

	pmc_enable_periph_clock(AT91C_ID_PIOA_B);
	pio_configure(recovery_button_pins);
}
#endif /* #if defined(CONFIG_NANDFLASH_RECOVERY) || defined(CONFIG_DATAFLASH_RECOVERY) */

#ifdef CONFIG_HW_INIT
void hw_init(void)
{
	/* Disable watchdog */
	at91_disable_wdt();

	/* At this stage the main oscillator is supposed to be enabled PCK = MCK = MOSC */
	pmc_init_pll(0);

	/* Configure PLLA = MOSC * (PLL_MULA + 1) / PLL_DIVA */
	pmc_cfg_plla(PLLA_SETTINGS);

	/* PCK = PLLA/2 = 3 * MCK */
	pmc_cfg_mck(BOARD_PRESCALER_MAIN_CLOCK);

	/* Switch MCK on PLLA output */
	pmc_cfg_mck(BOARD_PRESCALER_PLLA);

	/* Enable External Reset */
	writel(AT91C_RSTC_KEY_UNLOCK | AT91C_RSTC_URSTEN, AT91C_BASE_RSTC + RSTC_RMR);

	/* Init timer */
	timer_init();

#ifdef CONFIG_SCLK
	slowclk_enable_osc32();
#endif

	/* Initialize dbgu */
	initialize_dbgu();

#ifdef CONFIG_DDR2
	/* Initialize DDRAM Controller */
	ddramc_init();
#endif

#ifdef CONFIG_USER_HW_INIT
	hw_init_hook();
#endif

#if defined(CONFIG_NANDFLASH_RECOVERY) || defined(CONFIG_DATAFLASH_RECOVERY)
	/* Init the recovery buttons pins */
	recovery_buttons_hw_init();
#endif
}
#endif /* #ifdef CONFIG_HW_INIT */

#ifdef CONFIG_DATAFLASH
void at91_spi0_hw_init(void)
{
	/* Configure PIN for SPI0 */
	const struct pio_desc spi0_pins[] = {
		{"MISO",	AT91C_PIN_PA(11), 0, PIO_DEFAULT, PIO_PERIPH_A},
		{"MOSI",	AT91C_PIN_PA(12), 0, PIO_DEFAULT, PIO_PERIPH_A},
		{"SPCK",	AT91C_PIN_PA(13), 0, PIO_DEFAULT, PIO_PERIPH_A},
		{"NPCS",	CONFIG_SYS_SPI_PCS, 1, PIO_DEFAULT, PIO_OUTPUT},
		{(char *)0,	0, 0, PIO_DEFAULT, PIO_PERIPH_A},
	};

	/* Configure the PIO controller */
	pmc_enable_periph_clock(AT91C_ID_PIOA_B);
	pio_configure(spi0_pins);

	/* Enable the clock */
	pmc_enable_periph_clock(AT91C_ID_SPI0);
}
#endif /* #ifdef CONFIG_DATAFLASH */

#ifdef CONFIG_SDCARD
static void sdcard_set_of_name_board(char *of_name)
{
	strcpy(of_name, "at91sam9n12ek.dtb");
}
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
